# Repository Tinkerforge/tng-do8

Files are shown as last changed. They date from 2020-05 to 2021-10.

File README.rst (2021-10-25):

TNG DO8
=======

**This TNG module is currently in development.**

This repository contains the firmware source code and the hardware design
files. The documentation generator configs can be found at
https://github.com/Tinkerforge/generators

Repository Content
------------------

software/:
 * examples/: Examples for all supported languages
 * build/: Compiled files
 * src/: Source code of firmware
 * Makefile: Makefile to build project

hardware/:
 * Contains KiCad project files and additionally schematics as PDF

datasheets/:
 * Contains datasheets for sensors and complex ICs that are used

Hardware
--------

The hardware is designed with the open source EDA Suite KiCad
(http://www.kicad.org). Before you are able to open the files,
you have to install the Tinkerforge kicad-libraries
(https://github.com/Tinkerforge/kicad-libraries). You can either clone
them directly in hardware/ or clone them in a separate folder and
symlink them into hardware/
(ln -s kicad_path/kicad-libraries project_path/hardware). After that you
can open the .pro file in hardware/ with KiCad and from there view and
modify the schematics and the PCB layout.

Software
--------

If you want to do your own Brick/Bricklet firmware development we highly
recommend that you use our build environment setup script and read the
tutorial (https://www.tinkerforge.com/en/doc/Tutorials/Tutorial_Build_Environment/Tutorial.html).

To compile the C code we recommend you to install the newest GNU Arm Embedded
Toolchain (https://launchpad.net/gcc-arm-embedded/+download).
You also need to install bricklib2 (https://github.com/Tinkerforge/bricklib2).

You can either clone it directly in software/src/ or clone it in a
separate folder and symlink it into software/src/
(ln -s bricklib_path/bricklib2 project_path/software/src/). Finally make sure to
have CMake installed (http://www.cmake.org/cmake/resources/software.html).

After that you can build the firmware by invoking make in software/.
The firmware (.zbin) can then be found in software/build/ and uploaded
with brickv (click button "Flashing" on start screen).

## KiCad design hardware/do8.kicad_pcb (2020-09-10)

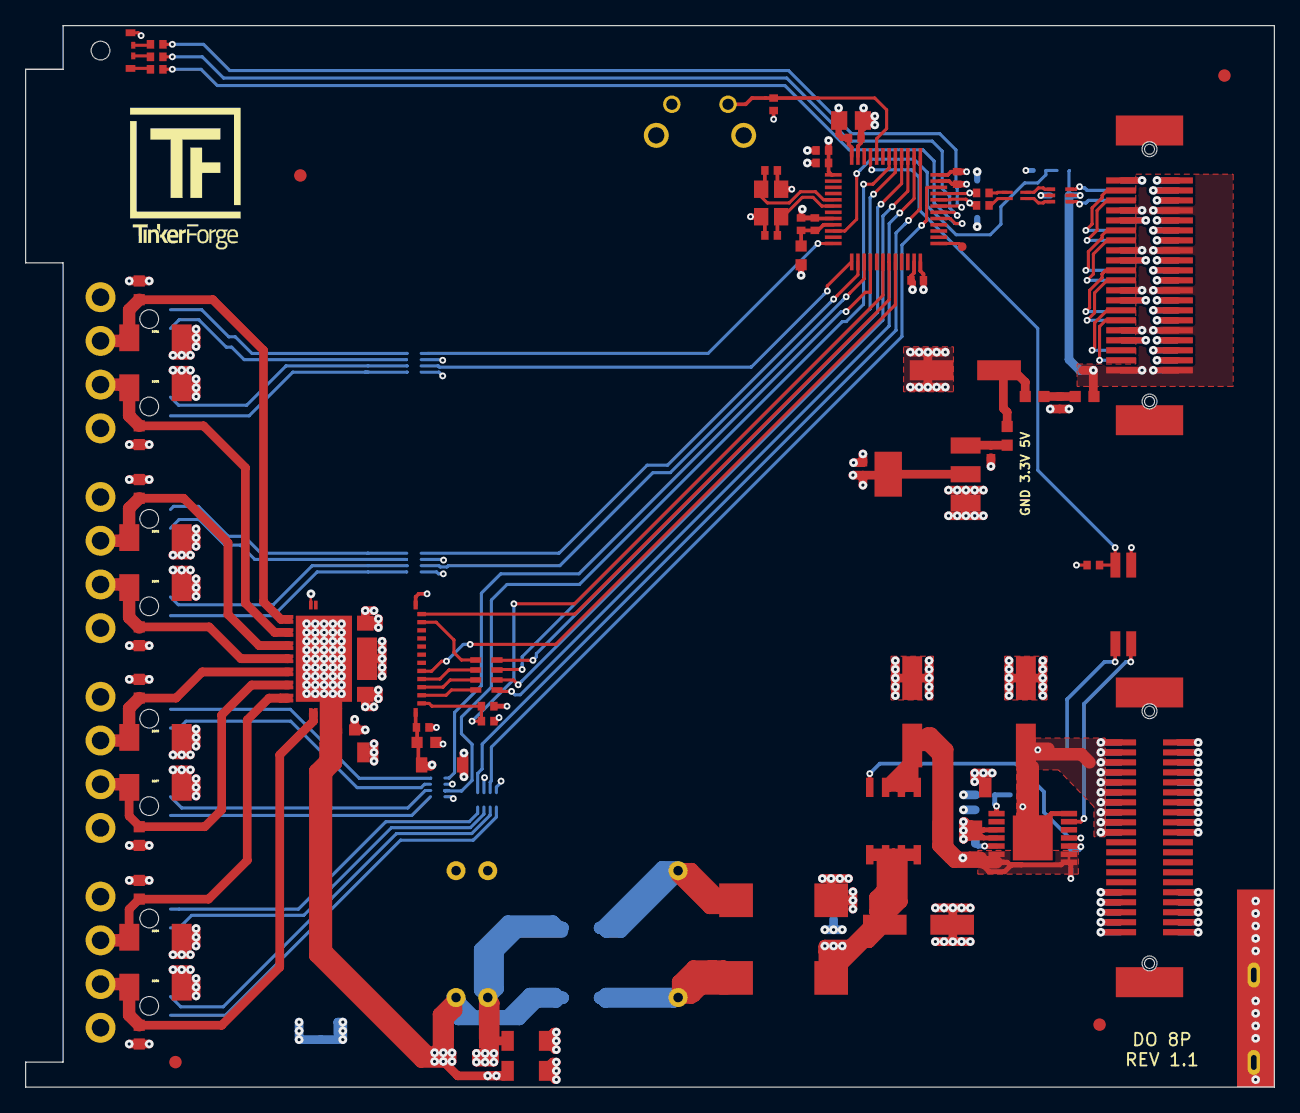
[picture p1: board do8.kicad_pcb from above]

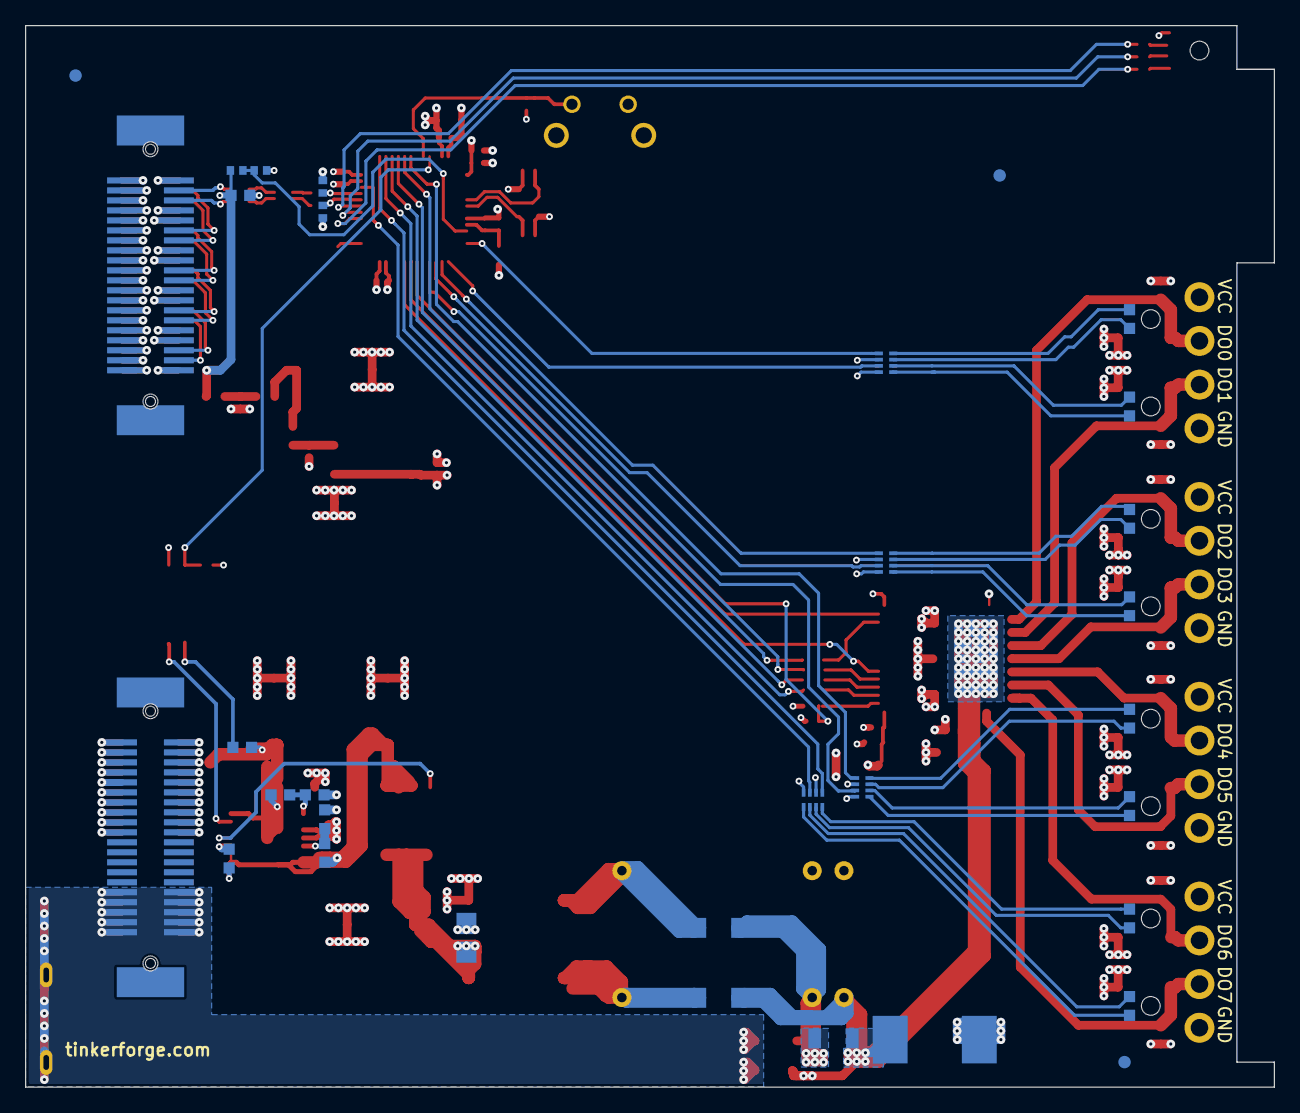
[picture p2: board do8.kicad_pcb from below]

Board: 4 copper layers, 100.0 x 85.0 mm, 115 parts (33 on the bottom side), 93 nets.

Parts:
C101, C102, C116, C117: 1uF; C0402F
C103, C104, C105, C106, C107, C112, C212: 100nF; C0402F
C108, C109: 33pF; C0402F
C110: 10uF; C0805E
C111: 100uF; ELKO_63
C113, C114: 47pF; C0402F
C115, C213: 2.2uF; C0603F
C118, C121: 10uF/50V; C1206
C119, C120: 0; C1206
C122, C123, C124: 100uF/35V; ELKO_63
C125, C126: 10uF/35V; C1206
C127, C128: 1nF/2kV; C1206
C202, C203, C204, C205, C206, C207, C209, C211: 22n/50V; C0603F
C208: 4.7uF/50V; C1206
C210: 100nF/50V; C0603F
C214: 15pF; C0402F
D101: 3.0SMI30CATR; SMC
D201, D202, D203, D204, D205, D206, D207, D208: SMBJ24CA; SMB
D209: SMF3.3; SOD-123FL
D210, D211, D212, D213, D214, D215, D216, D217: LED; LED-LP
Fiducial_Mark: VAL**; Fiducial_Mark
Fiducial_Mark#2, Fiducial_Mark#3, Fiducial_Mark#4, Fiducial_Mark#5, Fiducial_Mark#6, Fiducial_Mark#7: VAL**; Fiducial_Mark
J101: TNG-Power-TOP; TNG-40-TOP
J102: TNG-Power-BTM; TNG-40-BTM
J103: TNG-Data-TOP; TNG-40-TOP
J104: TNG-Data-BTM; TNG-40-BTM
L101: FB; R0603F
L102, L103, L104: INDUCTs; R0603F
L105: 744230900; WE-CNSW-0603
LED101: EASV3015RGBA0; LED-RGB-LP
P102: Debug; DEBUG_PAD
P103: PE; PE_Hook
P201: OUTPUT0; OQ_4P
P202: OUTPUT1; OQ_4P
P203: OUTPUT2; OQ_4P
P204: OUTPUT3; OQ_4P
Q101: FDS8449; SOIC-8-MOSFET
R101, R107, R108: 1k; R0402F
R102, R105: 0; R0402F
R103, R104: 22; R0402F
R106: 56; R0402F
R109: 10k; R0402F
R110, R115: 10k; R0603F
R111, R112: DNP; R0603F
R113: 22; R0603F
R114: 68k; R0603F
R116: VC1206K201R030; R1206
R201: 47k; R0402F
RP201: 180; 4X0603
RP202, RP203, RP204, RP205: 470; 4X0402
SW101: BOOT; TACT-6MM-HOR
T101: 744273222; WE-SL5
U101: STM32F070CBT6; LQFP48
U102: AZ1117EH; SOT-223
U103: 82400152; SOT563-SPEC
U104: DNP; TEL10
U105: TLP293; SOP4
U106: STEF01; HTSSOP14
U201: ISO8200AQ; TFQFPN32
X101: 8MHz; CRYSTAL_3225

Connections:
3V3: C101.1, C103.1, C104.1, C105.1, C106.1, C110.1, C116.1, C212.2, C213.2, D209.2, L101.1, LED101.1, R109.2, RP202.2, RP202.4, RP203.2, RP203.4, RP204.2, RP204.4, RP205.2, RP205.4, SW101.1, U101.1, U101.24, U101.36, U101.48, U102.2, U201.20
5VA: C115.1, J103.7, J103.8, J103.15, J103.16, J103.23, J103.24, J103.31, J103.32, J103.39, J103.40, J104.7, J104.8, J104.15, J104.16, J104.23, J104.24, J104.31, J104.32, J104.39, J104.40, L104.1, R107.1, U103.5
+5V: C111.1, L102.1, L103.2
AGND: C118.2, C120.1, C128.2, C202.1, C203.1, C204.1, C205.1, C206.1, C207.1, C208.1, C209.1, C210.1, C211.1, D101.2, D201.1, D202.1, D203.1, D204.1, D205.1, D206.1, D207.1, D208.1, P201.4, P202.4, P203.4, P204.4, R116.2, U104.10, U201.3, U201.TGND
AGNDA: C121.2, C122.2, C123.2, C124.2, C125.2, C126.2, J101.2, J101.4, J101.6, J101.8, J101.10, J101.12, J101.14, J101.16, J101.18, J101.20, J102.1, J102.3, J102.5, J102.7, J102.9, J102.11, J102.13, J102.15, J102.17, J102.19, R112.2, R115.2, T101.2, U106.3, U106.4
AIN0: R107.2, R108.1, U101.10
Earth: C127.2, C128.1, J101.31, J101.32, J101.33, J101.34, J101.35, J101.36, J101.37, J101.38, J101.39, J101.40, J102.31, J102.32, J102.33, J102.34, J102.35, J102.36, J102.37, J102.38, J102.39, J102.40, P103.1
GND: C101.2, C102.2, C103.2, C104.2, C105.2, C106.2, C107.2, C108.1, C109.1, C110.2, C111.2, C112.2, C113.2, C114.2, C115.2, C116.2, C117.2, C212.1, C213.1, C214.1, D209.1, J103.1, J103.2, J103.4, J103.6, J103.9, J103.10, J103.12, J103.14, J103.17, J103.18, J103.20, J103.22, J103.25, J103.26, J103.28, J103.30, J103.33, J103.34, J103.36, J103.38, J104.1, J104.2, J104.3, J104.5, J104.9, J104.10, J104.11, J104.13, J104.17, J104.18, J104.19, J104.21, J104.25, J104.26, J104.27, J104.29, J104.33, J104.34, J104.35, J104.37, R101.1, R108.2, R201.2, U101.8, U101.23, U101.35, U101.47, U102.1, U103.2, U105.3, U201.1, X101.3
LED0: RP202.1, U101.12
LED1: RP202.3, U101.13
LED2: RP203.1, U101.14
LED3: RP203.3, U101.15
LED4: RP204.1, U101.16
LED5: RP204.3, U101.42
LED6: RP205.1, U101.37
LED7: RP205.3, U101.34
LEDB: R106.1, U101.31
LEDG: R105.1, U101.30
LEDR: R102.1, U101.29
unnamed: C102.1, C107.1, L101.2, U101.9
unnamed: C108.2, U101.5, X101.2
unnamed: C109.2, U101.6, X101.1
unnamed: C112.1, L103.1, L104.2
unnamed: C117.1, L102.2, U102.3
unnamed: C119.2, T101.4, U104.16
unnamed: C120.2, T101.3, U104.1
unnamed: C121.1, C123.1, Q101.D, T101.1
unnamed: C202.2, D208.2, P204.3, U201.18, U201.19
unnamed: C203.2, D204.2, P204.2, U201.16, U201.17
unnamed: C204.2, D207.2, P203.3, U201.14, U201.15
unnamed: C205.2, D203.2, P203.2, U201.12, U201.13
unnamed: C206.2, D206.2, P202.3, U201.10, U201.11
unnamed: C207.2, D202.2, P202.2, U201.8, U201.9
unnamed: C209.2, D205.2, P201.3, U201.6, U201.7
unnamed: C211.2, D201.2, P201.2, U201.4, U201.5
unnamed: D210.1, RP202.7
unnamed: D210.2, RP202.8
unnamed: D211.1, RP202.5
unnamed: D211.2, RP202.6
unnamed: D212.1, RP203.7
unnamed: D212.2, RP203.8
unnamed: D213.1, RP203.5
unnamed: D213.2, RP203.6
unnamed: D214.1, RP204.7
unnamed: D214.2, RP204.8
unnamed: D215.1, RP204.5
unnamed: D215.2, RP204.6
unnamed: D216.1, RP205.7
unnamed: D216.2, RP205.8
unnamed: D217.1, RP205.5
unnamed: D217.2, RP205.6
unnamed: J103.3, J104.12
unnamed: J103.5, J104.14
unnamed: J103.11, J104.20
unnamed: J103.13, J104.22
unnamed: J103.19, J104.28
unnamed: J103.21, J104.30
unnamed: J103.27, J104.36
unnamed: J103.29, J104.38
unnamed: LED101.2, R106.2
unnamed: LED101.3, R105.2
unnamed: LED101.4, R102.2
unnamed: P102.1, U101.25
unnamed: Q101.G, U106.11
unnamed: R101.2, SW101.2, U101.44
unnamed: R110.2, U105.1
unnamed: R111.2, R112.1, U106.5
unnamed: R113.2, U106.10
unnamed: R114.2, R115.1, U106.1
unnamed: RP201.1, U201.22
unnamed: RP201.2, U201.23
unnamed: RP201.3, U201.24
unnamed: RP201.4, U201.31
OUT_EN: C214.2, R201.1, U101.18, U201.21
PWR_GOOD: R109.1, U101.45, U105.4
PWR_PG: U105.2, U106.13
SDI: RP201.6, U101.41
SDO: RP201.5, U101.40
USB-DM: C114.1, R104.2, U101.32
USB-DMA: J104.6, U103.4
USB-DMB: L105.1, U103.3
USB-DMC: L105.2, R104.1
USB-DP: C113.1, R103.2, U101.33
USB-DPA: J104.4, U103.6
USB-DPB: L105.4, U103.1
USB-DPC: L105.3, R103.1
VCC: C118.1, C119.1, C127.1, C208.2, C210.2, D101.1, P201.1, P202.1, P203.1, P204.1, R116.1, U104.9, U201.TVCC
VCCPWRA: C122.1, C126.1, J101.1, J101.3, J101.5, J101.7, J101.9, J101.11, J101.13, J101.15, J101.17, J101.19, J102.2, J102.4, J102.6, J102.8, J102.10, J102.12, J102.14, J102.16, J102.18, J102.20, R110.1, R114.1, U106.14, U106.EXP
VO: C124.1, C125.1, Q101.S, R111.1, R113.1, U106.6, U106.7, U106.8, U106.9
~CLK: RP201.7, U101.39
~FAULT: U101.19, U201.32
~PGOOD: U101.20, U201.25
~SS: RP201.8, U101.38

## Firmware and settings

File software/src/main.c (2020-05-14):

/* tng-do8
 * Copyright (C) 2019 Olaf Lüke <olaf@tinkerforge.com>
 *
 * main.c: Initialization for TNG DO8
 *
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
 * You should have received a copy of the GNU Lesser General Public
 * License along with this library; if not, write to the
 * Free Software Foundation, Inc., 59 Temple Place - Suite 330,
 * Boston, MA 02111-1307, USA.
 */

#include "configs/config.h"

#include "bricklib2/tng/tng.h"
#include "bricklib2/logging/logging.h"

#include "do8.h"

int main(void) {
	logging_init();
	logd("Start TNG DO8\n\r");

	do8_init();

	while(true) {
		tng_tick();
		do8_tick();
	}
}

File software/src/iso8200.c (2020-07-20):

/* tng-do8
 * Copyright (C) 2019-2020 Olaf Lüke <olaf@tinkerforge.com>
 *
 * iso8200.c: Driver for 8 digital outputs
 *
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
 * You should have received a copy of the GNU Lesser General Public
 * License along with this library; if not, write to the
 * Free Software Foundation, Inc., 59 Temple Place - Suite 330,
 * Boston, MA 02111-1307, USA.
 */

#include "iso8200.h"

#include "configs/config_iso8200.h"
#include "bricklib2/os/coop_task.h"
#include "bricklib2/logging/logging.h"
#include "bricklib2/tng/tng_led.h"

ISO8200 iso8200;
CoopTask iso8200_task;

void iso8200_task_tick(void) {
	while(true) {
		coop_task_sleep_ms(1);
	}
}

// Sets output channel, returns fault condition
uint8_t iso8200_set_output(const uint8_t output) {
	uint8_t tx = output;
	uint8_t rx = 0;

	HAL_GPIO_WritePin(ISO8200_SPI_CS_PORT, ISO8200_SPI_CS_PIN, GPIO_PIN_RESET);
	HAL_SPI_TransmitReceive(&iso8200.spi, &tx, &rx, 1, ISO8200_SPI_TIMEOUT);
	HAL_GPIO_WritePin(ISO8200_SPI_CS_PORT, ISO8200_SPI_CS_PIN, GPIO_PIN_SET);

	return rx;
}

void iso8200_init_spi(void) {
	// Enable clocks
	__HAL_RCC_SPI1_CLK_ENABLE();
	__HAL_RCC_GPIOA_CLK_ENABLE();
	__HAL_RCC_GPIOB_CLK_ENABLE();

	// Configure CLK
	GPIO_InitTypeDef gpio_clk = {
		.Pin       = ISO8200_SPI_CLK_PIN,
		.Mode      = GPIO_MODE_AF_PP,
		.Pull      = GPIO_NOPULL,
		.Speed     = GPIO_SPEED_FREQ_HIGH,
		.Alternate = ISO8200_SPI_CLK_AF
	};
	HAL_GPIO_Init(ISO8200_SPI_CLK_PORT, &gpio_clk);

	// Configure MOSI
	GPIO_InitTypeDef gpio_mosi = {
		.Pin       = ISO8200_SPI_MOSI_PIN,
		.Mode      = GPIO_MODE_AF_PP,
		.Pull      = GPIO_NOPULL,
		.Speed     = GPIO_SPEED_FREQ_HIGH,
		.Alternate = ISO8200_SPI_MOSI_AF
	};
	HAL_GPIO_Init(ISO8200_SPI_MOSI_PORT, &gpio_mosi);

	// Configure MISO
	GPIO_InitTypeDef gpio_miso = {
		.Pin       = ISO8200_SPI_MISO_PIN,
		.Mode      = GPIO_MODE_AF_PP,
		.Pull      = GPIO_NOPULL,
		.Speed     = GPIO_SPEED_FREQ_HIGH,
		.Alternate = ISO8200_SPI_MISO_AF
	};
	HAL_GPIO_Init(ISO8200_SPI_MISO_PORT, &gpio_miso);

	// Configure CS
	GPIO_InitTypeDef gpio_cs = {
		.Pin       = ISO8200_SPI_CS_PIN,
		.Mode      = GPIO_MODE_OUTPUT_PP,
		.Pull      = GPIO_NOPULL,
		.Speed     = GPIO_SPEED_FREQ_HIGH,
	};
	HAL_GPIO_Init(ISO8200_SPI_CS_PORT, &gpio_cs);

	// Reset
	__HAL_RCC_SPI1_FORCE_RESET();
	__HAL_RCC_SPI1_RELEASE_RESET();

	iso8200.spi.Instance               = ISO8200_SPI_INSTANCE;
	iso8200.spi.Init.BaudRatePrescaler = SPI_BAUDRATEPRESCALER_256;
	iso8200.spi.Init.Direction         = SPI_DIRECTION_2LINES;
	iso8200.spi.Init.CLKPhase          = SPI_PHASE_1EDGE;
	iso8200.spi.Init.CLKPolarity       = SPI_POLARITY_LOW;
	iso8200.spi.Init.CRCCalculation    = SPI_CRCCALCULATION_DISABLE;
	iso8200.spi.Init.CRCPolynomial     = 7;
	iso8200.spi.Init.DataSize          = SPI_DATASIZE_8BIT;
	iso8200.spi.Init.FirstBit          = SPI_FIRSTBIT_MSB;
	iso8200.spi.Init.NSS               = SPI_NSS_SOFT; 
	iso8200.spi.Init.NSSPMode          = SPI_NSS_PULSE_DISABLE;
	iso8200.spi.Init.TIMode            = SPI_TIMODE_DISABLE;
	iso8200.spi.Init.Mode              = SPI_MODE_MASTER;	
	HAL_SPI_Init(&iso8200.spi);
}

void iso8200_init(void) {
	memset(&iso8200, 0, sizeof(ISO8200));

	iso8200_init_spi();

	// Configure Output Enable
	GPIO_InitTypeDef gpio_out_en = {
		.Pin       = ISO8200_OUT_EN_PIN,
		.Mode      = GPIO_MODE_OUTPUT_PP,
		.Pull      = GPIO_NOPULL,
		.Speed     = GPIO_SPEED_FREQ_HIGH,
	};
	HAL_GPIO_Init(ISO8200_OUT_EN_PORT, &gpio_out_en);
	HAL_GPIO_WritePin(ISO8200_OUT_EN_PORT, ISO8200_OUT_EN_PIN, GPIO_PIN_SET);

	iso8200_set_output(0);
}

uint8_t test = 0;
void iso8200_tick(void) {
	iso8200.fault = iso8200_set_output(iso8200.value);
	if(iso8200.fault != 0) {
		logd("Fault: %b\n\r", iso8200.fault);
	}

	for(uint8_t i = 0; i < ISO8200_CHANNEL_NUM; i++) {
		tng_led_channel_set(i, iso8200.value & (1 << i));
	}

	if(iso8200.fault) {
		tng_led_status_set(255, 0, 0);
	} else {
		tng_led_status_set(0, 0, 0);
	}

//	coop_task_tick(&iso8200_task);
}

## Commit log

2019-11-22 do8 nearly finished
    [do8.kicad_pcb, do8.sch, outputs.sch]
2019-11-25 some routing
    [do8.kicad_pcb]
2019-11-26 completely routed
    [do8.kicad_pcb]
2019-11-28 outline update
    [do8.kicad_pcb]
2019-12-10 fix name
    [do8.kicad_pcb]
2019-12-23 update rgb led drill diameter
    [do8.kicad_pcb]
2019-12-30 fix inductor footprint
    [do8.kicad_pcb, do8.sch]
2020-03-02 fix description
    [do8.kicad_pcb]
2020-03-02 add hook footprint
    [do8.kicad_pcb]
2020-05-14 change value
    [do8.kicad_pcb, outputs.sch]
2020-05-14 specify tbd
    [do8.kicad_pcb, do8.sch, outputs.sch]
2020-07-07 fix diodes
    [do8.kicad_pcb, outputs.sch]
2020-07-20 Add ISO8200 driver
2020-07-27 Add TIM defines for status LEDs
2020-09-04 version 1.1.
    fix footprints
    [do8.kicad_pcb, do8.sch, outputs.sch]
2020-09-07 fix values
    [do8.kicad_pcb, do8.sch]
2020-09-07 fix footprint
    [do8.kicad_pcb, do8.sch]
2020-09-08 fix routing
    [do8.kicad_pcb, outputs.sch]
2020-09-08 all footprints updated
    [do8.kicad_pcb]
2020-09-09 remove galvanic isolation as default
    [do8.kicad_pcb, do8.sch]
2020-09-10 fix 3d stuff
    [do8.kicad_pcb]
2021-10-25 Update KiCad link
    https://www.kicad.org/blog/2021/10/Avoid-links-to-former-kicad-domain/

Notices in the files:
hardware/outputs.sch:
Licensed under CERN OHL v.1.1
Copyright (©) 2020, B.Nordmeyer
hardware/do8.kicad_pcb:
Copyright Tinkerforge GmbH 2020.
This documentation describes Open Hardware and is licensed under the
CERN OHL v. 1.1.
